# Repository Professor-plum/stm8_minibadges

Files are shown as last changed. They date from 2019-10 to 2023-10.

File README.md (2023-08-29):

# stm8_minibadges
Repository of mini badges using the stm8s001j3.

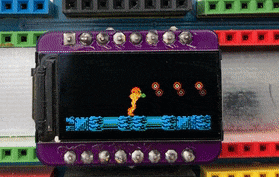
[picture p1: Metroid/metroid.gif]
Metroid

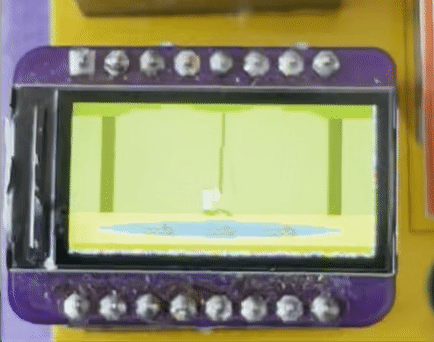
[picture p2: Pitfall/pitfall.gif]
Pitfall

Doom
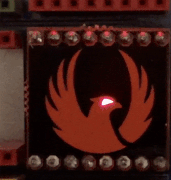
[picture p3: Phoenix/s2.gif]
Phoenix


This repo contains all the source code and eagle files for the mini badges I've designed using the STM8S001J3 microprocessor. I've loved this little chip as it's cheaper than an ATTiny and extremely versatile. The package design leaves a bit to be desired as it wastes one pin for a required cap and the pin 1 marking is horrible but for $.23 you can't complain much.

## Assembly

I'd recommend soldering the LCD down first, followed by the STM8 chip (note the orientation) then the resistor and capacitor. Finally, solder on the pin header legs once all the surface mount components are down. 

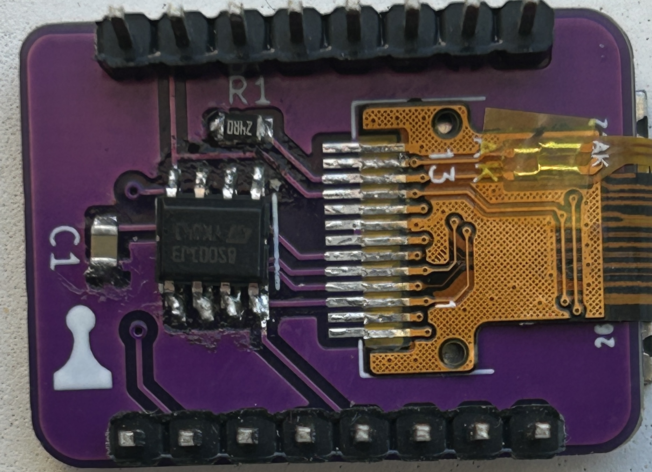
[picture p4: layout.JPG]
Layout


## Flashing

In all my stm8 projects I do bare metal programming and utilize no libraries (I'm usually wanting to make the most of that 8K flash)

There’s also a lot of code reuse between these projects. I could probably do better at managing that, meh...

The following tools are required to compile and flash the chips:
* [ST-Link V2](http://www.ebay.com/sch/i.html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)
* [sdcc](https://sourceforge.net/projects/sdcc/files/snapshot_builds/)
* [stm8flash](https://github.com/vdudouyt/stm8flash)

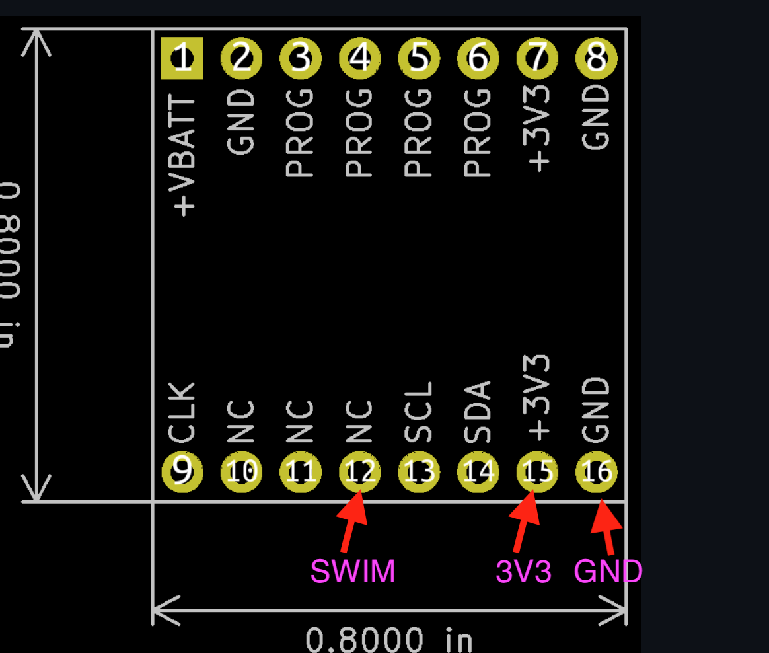
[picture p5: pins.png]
Pinmap


To flash the badge there are only three that need to be connected from the ST-Link to the minibadge. 
* That is 3V3 to the lower 3V
* GND to ether GND
* SWIM to NC12 (4th pin from the right on the bottom row)

Usually, the process for compiling and flashing is the same for all projects. That is:

```bash
>sdcc -lstm8 -mstm8 --out-fmt-ihx main.c
>stm8flash -c stlinkv2 -p stm8s001j3 -w main.ihx
```

The stm8flash command usually needs to be executed twice, the first rarely takes.
A successful flash outputs something similar to this

```
Determine FLASH area
Due to its file extension (or lack thereof), "main.ihx" is considered as INTEL HEX format!
4456 bytes at 0x8000... OK
Bytes written: 4456
```

I apologize for the lack of code comments but I don’t really care enough to do something about it :/

The colors may be inverted depending on the TFT LCD type you have. The simple fix is to locate the line `ST7735_Write(ST7735_INVOFF, CMD);` in the main.c file and change it to `ST7735_Write(ST7735_INVON, CMD);` or vice versa. Then recompile and reflash.

The official documentation for this chip can be found at https://www.st.com/resource/en/datasheet/stm8s001j3.pdf

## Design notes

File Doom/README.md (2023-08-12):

# Doom Mini Badge!

Doom

## Bill of Materials 
* 0.96" 80x160 ST7735 TFT LCD Display
* STMS001J3
* 22 Ohm 0603 Resistor
* 1uF 0603 Capacitor
* Pin headers

Same hardware as the Metroid Mini Badge

Doom face from orignal game. Shows random expression (always full health)

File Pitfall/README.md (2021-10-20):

# Pitfall Mini Badge!

Pitfall

## Bill of Materials 
* 0.96" 80x160 ST7735 TFT LCD Display
* STMS001J3
* 22 Ohm 0603 Resistor
* 1uF 0603 Capacitor
* Pin headers

Same hardware as the Metroid Mini Badge

The sketch is a tribute to the original Atari Pitfall! programers who wrote the whole game in 4K. (This minibadge takes more than that just for this short animation)

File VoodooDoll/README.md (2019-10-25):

# Voodoo Doll SOA

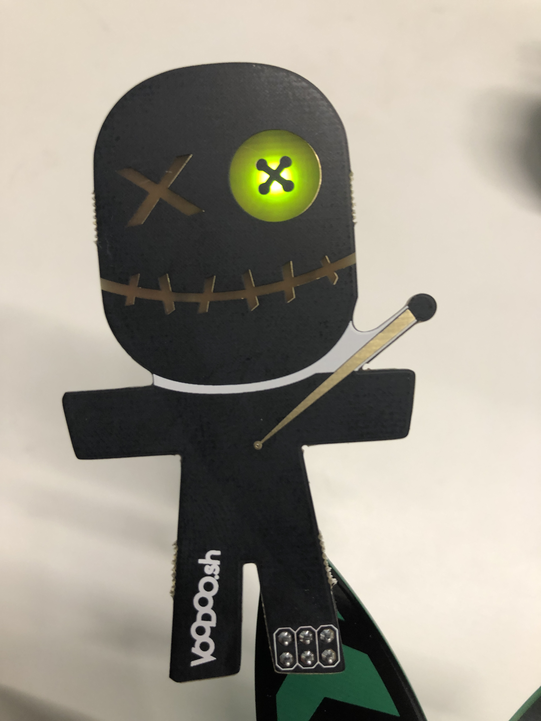
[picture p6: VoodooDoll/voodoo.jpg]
Voodoo Doll


This isn't a mini badge per say but it’s very similar and based off the same chip so I’m including it. I can’t seem to locate the Eagle files for this project but once I do I’ll add them to the repo.

## Bill of Materials
* STMS001J3
* LSG T77K-JL Red/Green LED
* 2x 1K Ohm 0603 Resistor
* 1M Ohm 0603 Resistor
* 1uF 0603 Capacitor
* Cr2032 battery holder (optional)
* 2x3 pin header (optional if using battery)

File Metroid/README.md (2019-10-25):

# Metroid Mini Badge!

Metroid

## Bill of Materials 
* 0.96" 80x160 ST7735 TFT LCD Display
* STMS001J3
* 22 Ohm 0603 Resistor
* 1uF 0603 Capacitor
* Pin headers

The 8K of flash isn't enough space to hold 65536 color sprites for the full animation. since the NES only used 16 colors I'm storing 2 pixels per byte (4 bits each).  The convert.py script does this for me.

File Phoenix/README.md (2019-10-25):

# Phoenix mini badge

Phoenix

This badge had a CTF associated with it. The badge face is touch sensitive and would display a URL on the main badge when touched. There were some issues with the 2019 SAINTCON badge and the link would display in like 1:100 touches.

The eye slowly pulses normally and blinks rapidly when touched

## Bill of Materials
* STM8S001J3
* LS T77K-K1 Red LED
* 470 Ohm 1206 Resistor
* 1M Ohm 1206 Resistor
* 1uF 1206 Capacitor
* pin headers

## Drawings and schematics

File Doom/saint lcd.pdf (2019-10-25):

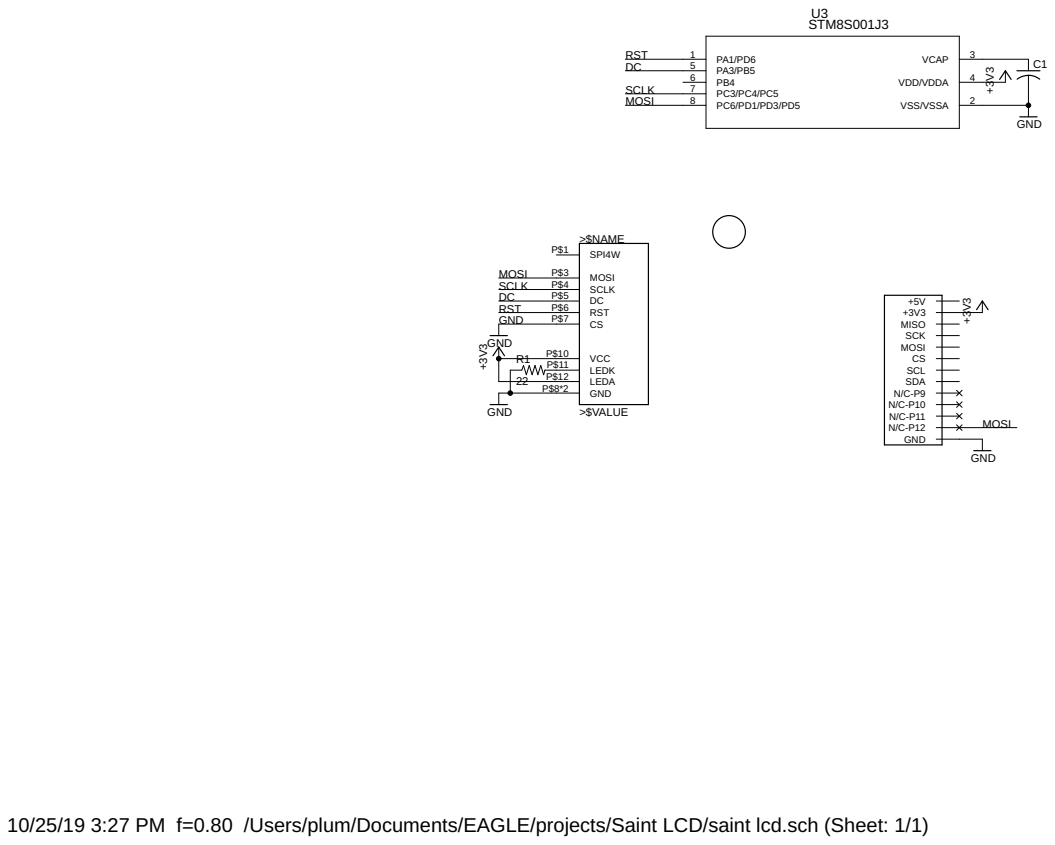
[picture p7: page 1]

10/25/19 3:27 PM f=0.80 /Users/plum/Documents/EAGLE/projects/Saint LCD/saint lcd.sch (Sheet: 1/1)

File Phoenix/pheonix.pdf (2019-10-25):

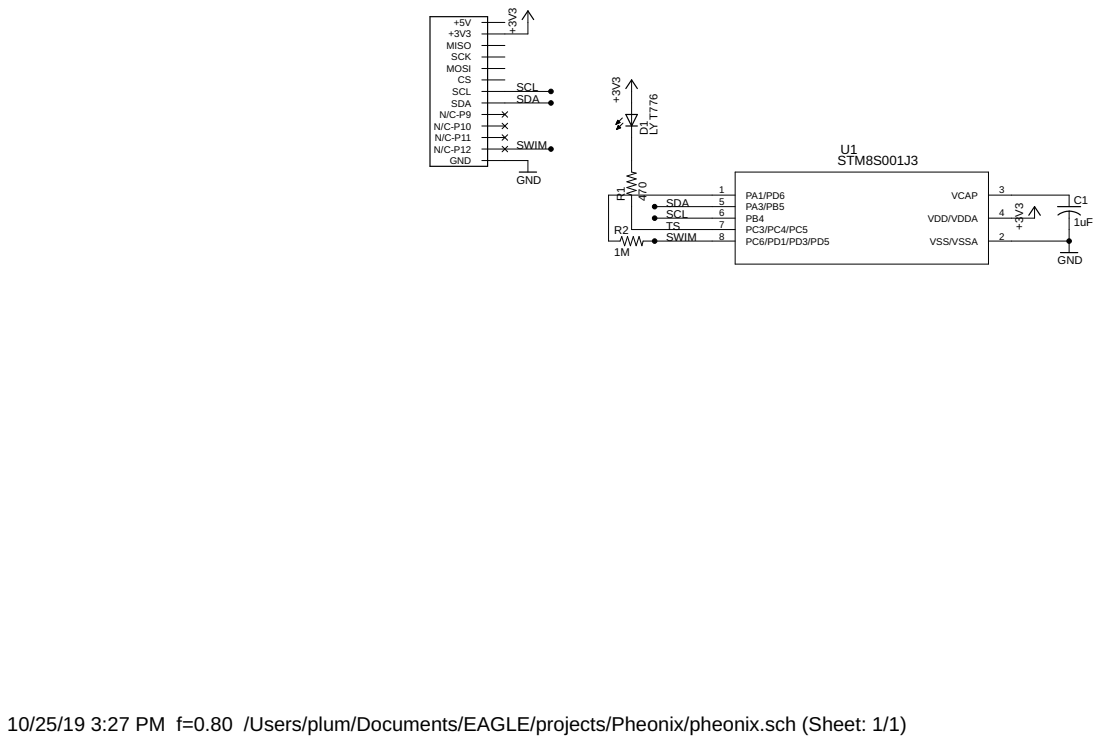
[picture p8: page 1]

10/25/19 3:27 PM f=0.80 /Users/plum/Documents/EAGLE/projects/Pheonix/pheonix.sch (Sheet: 1/1)

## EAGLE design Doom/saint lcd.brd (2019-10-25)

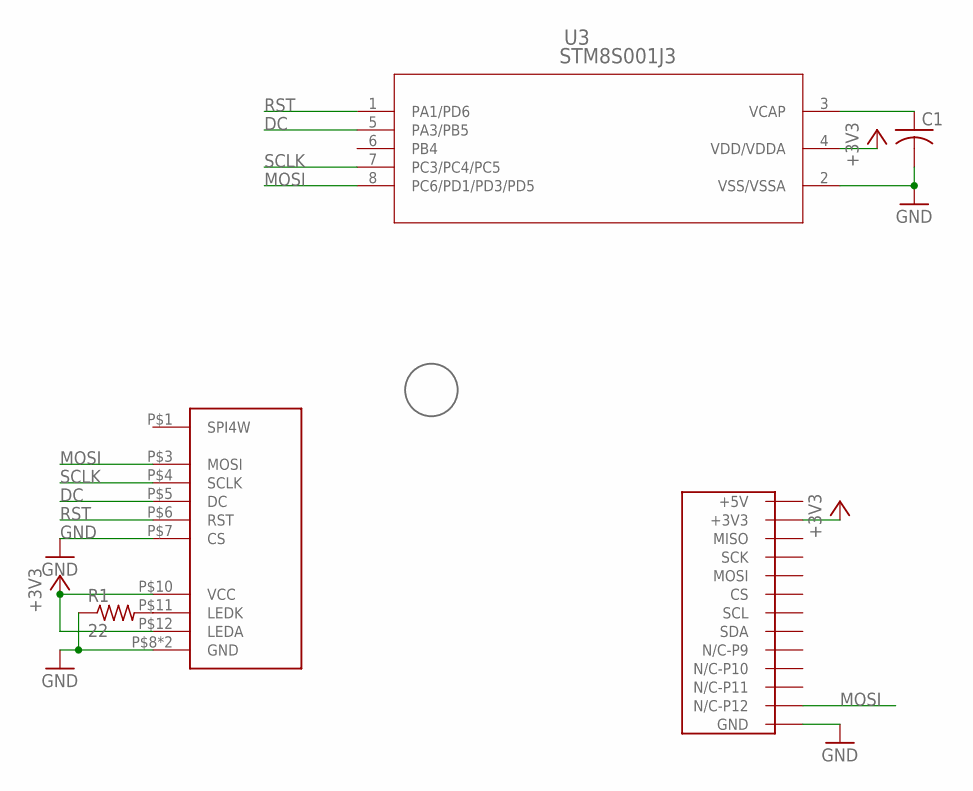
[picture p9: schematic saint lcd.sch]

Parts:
C1: C-USC0603; C0603
R1: 22; R0603
U3: STM8S001J3; SOD8N_4P9X6
U$1: BADGE64FOOTPRINT; BADGE64-FOOTPRINT
U$2: FPC13
U$3: PLUM

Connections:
+3V3: U3.4 (VDD/VDDA), U$1.+3V3-P7 (+3V3), U$1.+3V3-P15 (+3V3), U$2.P$10 (VCC), U$2.P$12 (LEDA)
+5V: U$1.+5V
DC: U3.5 (PA3/PB5), U$2.P$5 (DC)
GND: C1.2, R1.1, U3.2 (VSS/VSSA), U$1.GND-P2 (GND), U$1.GND-P8 (GND), U$1.GND-P16 (GND), U$2.P$7 (CS), U$2.P$8 (GND), U$2.P$13 (GND)
MOSI: U3.8 (PC6/PD1/PD3/PD5), U$1.NC-P12 (N/C-P12), U$2.P$3 (MOSI)
unnamed: R1.2, U$2.P$11 (LEDK)
unnamed: C1.1, U3.3 (VCAP)
RST: U3.1 (PA1/PD6), U$2.P$6 (RST)
SCLK: U3.7 (PC3/PC4/PC5), U$2.P$4 (SCLK)

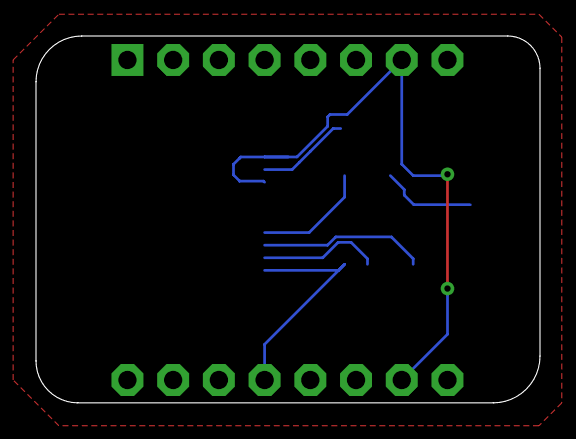
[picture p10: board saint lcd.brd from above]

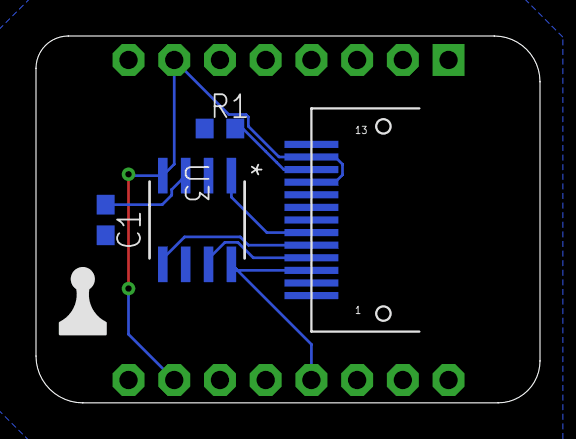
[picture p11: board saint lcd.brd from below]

Board: 2 copper layers, 28.0 x 20.4 mm, 6 parts (5 on the bottom side), 8 nets.

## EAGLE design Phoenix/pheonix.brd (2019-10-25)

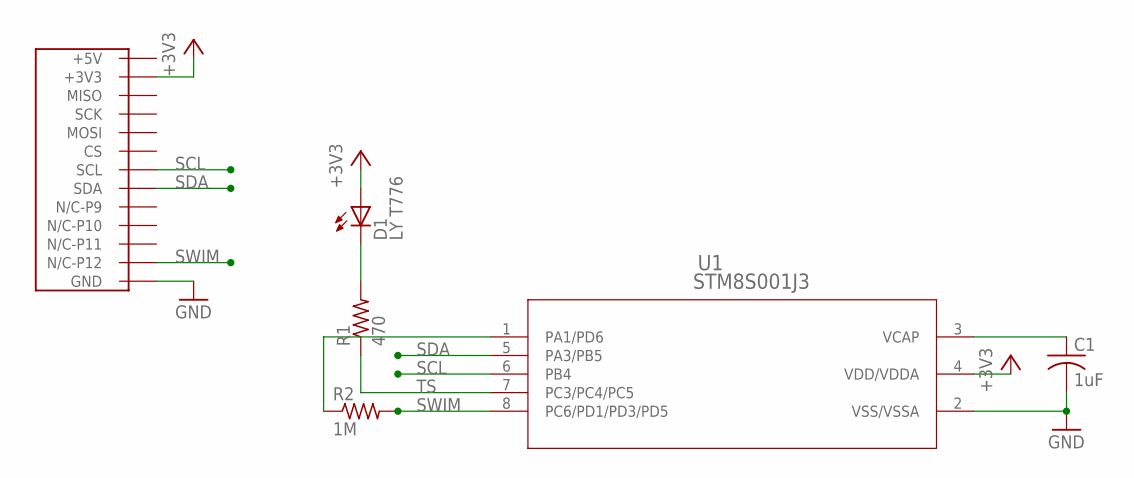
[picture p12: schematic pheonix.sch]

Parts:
C1: 1uF; C1206
D1: LY T776; P-LCC-2-TOPLED-RG-SMALL
R1: 470; M1206
R2: 1M; M1206
U1: STM8S001J3; SOD8N_4P9X6
U$1: BADGE64FOOTPRINT; BADGE64-FOOTPRINT

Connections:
+3V3: D1.A, U1.4 (VDD/VDDA), U$1.+3V3-P7 (+3V3), U$1.+3V3-P15 (+3V3)
+5V: U$1.+5V
GND: C1.2, U1.2 (VSS/VSSA), U$1.GND-P2 (GND), U$1.GND-P8 (GND), U$1.GND-P16 (GND)
unnamed: D1.C, R1.2
unnamed: R1.1, U1.7 (PC3/PC4/PC5)
unnamed: C1.1, U1.3 (VCAP)
SCL: U1.6 (PB4), U$1.SCL
SDA: U1.5 (PA3/PB5), U$1.SDA
SWIM: R2.2, U1.8 (PC6/PD1/PD3/PD5), U$1.NC-P12 (N/C-P12)
TS: R2.1, U1.1 (PA1/PD6)

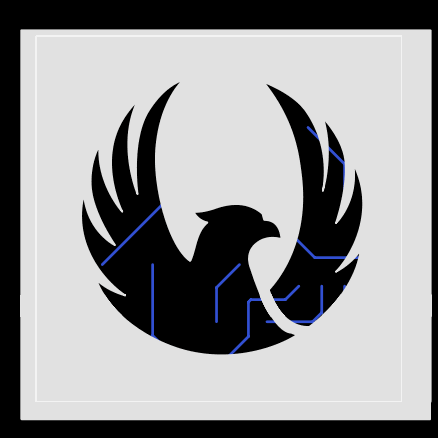
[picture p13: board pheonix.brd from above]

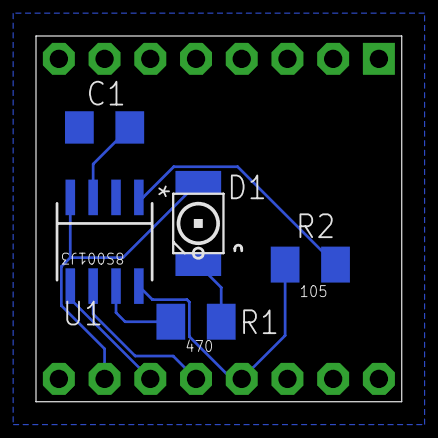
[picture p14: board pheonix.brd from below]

Board: 2 copper layers, 20.3 x 20.3 mm, 6 parts (5 on the bottom side), 9 nets.

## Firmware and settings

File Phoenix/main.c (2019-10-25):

#include <stdint.h>
#include <stdio.h>

#include "stm8s.h"

#define TSPAN	15
#define SINC	256
const uint16_t sin_tbl[] = {
266, 277, 287, 298, 310, 321, 333, 345, 357, 370, 382, 395, 408, 422, 435, 449, 463, 477, 491, 506, 520, 535, 550, 565, 580, 595, 610, 625, 640, 655, 670, 685, 700, 715, 729, 744, 758, 772, 786, 800, 813, 826, 839, 851, 863, 875, 886, 897, 907, 917, 926, 935, 943, 950, 957, 964, 969, 974, 979, 983, 986, 988, 990, 991, 991, 991, 990, 988, 986, 983, 979, 974, 969, 964, 957, 950, 943, 935, 926, 917, 907, 897, 886, 875, 863, 851, 839, 826, 813, 800, 786, 772, 758, 744, 729, 715, 700, 685, 670, 655, 640, 625, 610, 595, 580, 565, 550, 535, 520, 506, 491, 477, 463, 449, 435, 422, 408, 395, 382, 370, 357, 345, 333, 321, 310, 298, 287, 277, 266, 256, 246, 236, 227, 218, 209, 200, 191, 183, 175, 167, 160, 153, 146, 139, 132, 126, 119, 113, 108, 102, 97, 91, 86, 82, 77, 72, 68, 64, 60, 56, 52, 49, 45, 42, 39, 36, 33, 31, 28, 26, 23, 21, 19, 17, 15, 13, 12, 10, 9, 8, 6, 5, 4, 3, 3, 2, 1, 1, 0, 0, 0, 0, 0, 0, 0, 0, 0, 1, 1, 2, 3, 3, 4, 5, 6, 8, 9, 10, 12, 13, 15, 17, 19, 21, 23, 26, 28, 31, 33, 36, 39, 42, 45, 49, 52, 56, 60, 64, 68, 72, 77, 82, 86, 91, 97, 102, 108, 113, 119, 126, 132, 139, 146, 153, 160, 167, 175, 183, 191, 200, 209, 218, 227, 236, 246, 256,
};


#define SENSE_PIN (1<<1)
#define LOAD_PIN (1<<6)
#define I2C_SLAVE_ADDR	0x41


typedef enum {
    Idle,
    Ready,
    SentType,
    SendingSize,
    SentSize,
    SendingMessage,
    SentMessage,
} i2cState;

i2cState _is = Idle;

uint8_t i2c_idx=0;
const char disp2[] = "http://bit.ly/Stage2SC";

void opt_write() {
    /* new value for OPT5 (default is 0x00) */
    uint8_t opt2 = 0x01;
    /* unlock EEPROM */
    FLASH_DUKR = FLASH_DUKR_KEY1;
    FLASH_DUKR = FLASH_DUKR_KEY2;
    while (!(FLASH_IAPSR & (1 << FLASH_IAPSR_DUL)));
    /* unlock option bytes */
    FLASH_CR2 |= (1 << FLASH_CR2_OPT);
    FLASH_NCR2 &= ~(1 << FLASH_NCR2_NOPT);
    /* write option byte and it's complement */
    OPT2 = opt2;
    NOPT2 = ~opt2;
    /* wait until programming is finished */
    while (!(FLASH_IAPSR & (1 << FLASH_IAPSR_EOP)));
    /* lock EEPROM */
    FLASH_IAPSR &= ~(1 << FLASH_IAPSR_DUL);
}

unsigned int clock(void)
{
	unsigned char h = TIM1_CNTRH;
	unsigned char l = TIM1_CNTRL;
	return((unsigned int)(h) << 8 | l);
}

void init_clock(void) {
	CLK_CKDIVR = 0x00; // Set the frequency to 2 MHz
	CLK_PCKENR1 = 0xb9; // Enable Timers 1, 2, 4, i2c
	CLK_PCKENR2 = 0x73; //off
	//CLK_PCKENR1 = 0xFF; // Enable all peripherals
}

void init_tim1(void) {
	// Configure timer
	TIM1_PSCRH = 0x3e; // 1000 ticks per second 1Khz
	TIM1_PSCRL = 0x80;
	TIM1_CR1 = 0x01; // Enable timer
	

	//TIM1_CNTRH = 0; //reset counter
	//TIM1_CNTRL = 0;
}

void init_tim2(void) {
	TIM2_PSCR = 0x05; //Prescaler 32
	TIM2_ARRH = 0x03; //Autoreload 1000
	TIM2_ARRL = 0xe8;

	TIM2_CCER1 = 0x03; //Enable Channel 1 output | Compare low
	TIM2_CCMR1 = 0x60; // Compare mode PWM1 (changed from 0x78)
	TIM2_EGR |= 0x01;
	TIM2_CR1 = 0x81; //Enable timer2
}

inline void port_init() {
    PA_DDR |= 0x4; // PA2
	PA_CR1 |= 0x4;
	PA_ODR &= ~0x4;

	PB_DDR |= 0xcf; //PB1, PB2, PB3, PB6, PB7
	PB_CR1 |= 0xcf;
	PB_ODR &= ~0xcf;

	PC_DDR |= 0x86; //PC1, PC2, PC7
	PC_CR1 |= 0x86;
	PC_ODR &= ~0x86;

	PD_DDR |= 0x95; //PD0, PD2, PD4, PD7
	PD_CR1 |= 0x95;
	PD_ODR &= ~0x95;

	PE_DDR |= 0x40; //PE5
	PE_CR1 |= 0x40;
	PE_ODR &= ~0x40;

	PF_DDR |= 0x80; //PF7
	PF_CR1 |= 0x80;
	PF_ODR &= ~0x80;

}

void uart_init() {
    /* Configure RX and TX pins */
    //PD_DDR = 0xBF;
    //PD_CR1 = 0xFF;
    PD_DDR |= (1<<5); //PD5 output
    PD_CR1 |= (1<<5); //PD5 push-pull
    
    /* Enable TX */
    UART1_CR2 = UART_CR2_TEN;
    /* 1 stop bit */
    UART1_CR3 &= ~(UART_CR3_STOP1 | UART_CR3_STOP0);
    /* 9600 baud, 16MHz, Error:0.08%   */
    UART1_BRR2 = 0x03;
    UART1_BRR1 = 0x68;
}

void tim2_pwm1(uint16_t val) {
	TIM2_CCR1H = val >> 8;
	TIM2_CCR1L = val & 0xff;

}

#define CAP_TIMEOUT	256 //should be muchlower now

long readCapTouch() {
	//long i;
	PD_ODR |= LOAD_PIN; //send high
	PD_ODR &= ~SENSE_PIN; //low
	PD_DDR |= SENSE_PIN; //output
	PD_CR1 |= SENSE_PIN; //push/pull
	//for (i=0; i<100; ++i)
	//	__asm__ ("nop"); 
	
	PD_CR1 &= ~SENSE_PIN; //float
	PD_DDR &= ~SENSE_PIN; //recv input

	/*//PB_ODR &= ~(1<<4); //send low
	//PC_DDR &= ~((1<<3) | (1<<4) | (1<<5)); //PC3,4,5 input
	PC_DDR |= (1<<3) | (1<<4) | (1<<5); //recv ouput
	PC_ODR &= ~(1<<4); //recv low
	PC_DDR &= ~((1<<3) | (1<<4) | (1<<5)); //PC3,4,5 input
	for (i=0; i<1000; ++i)
		__asm__ ("nop"); 
	PB_ODR |= (1<<4); //send high
	PB_CR1 |= (1<<4);*/

	long count=0;
	while ((PD_IDR & SENSE_PIN)==0) {
		count++;
		if (count > CAP_TIMEOUT){
			break;
		}
	}

	PD_ODR |= SENSE_PIN; //high
	PD_DDR |= SENSE_PIN; //output
	PD_CR1 |= SENSE_PIN; //push/pull
	PD_ODR &= ~LOAD_PIN; //send low
	
	//for (i=0; i<100; ++i)
	//	__asm__ ("nop"); 
	
	PD_CR1 &= ~SENSE_PIN; //float
	PD_DDR &= ~SENSE_PIN; //recv input

	/*//PC_ODR |= (1<<4); //recv high
	PC_DDR |= (1<<3) | (1<<4) | (1<<5); //recv ouput
	PC_ODR |= (1<<4); //recv high
	for (i=0; i<1000; ++i)
		__asm__ ("nop"); 
	PC_DDR &= ~((1<<3) | (1<<4) | (1<<5)); //PC3,4,5 input
	PB_ODR &= ~(1<<4); //send low
	PB_CR1 &= ~(1<<4);*/
	
	long count2=0;
	while ((PD_IDR & SENSE_PIN)) {
		count2++;
		if (count2 > CAP_TIMEOUT)
			break;
	}
	//printf("Measure %ld + %ld\r\n", count, count2);
	return count+count2;
}

long rawCapSample(int count) {
	long total = 0;
	for (int i=0; i< count; ++i) {
		long t = readCapTouch();
		total += t;
	}
	return total;
}

/**
 * Initialize I2C at 100KHz standard mode.
 */
void i2c_init() {
    /* Disable I2C */
    I2C_CR1 &= ~I2C_CR1_PE;
    //I2C_CR1 |= I2C_CR1_ENGC;
    I2C_FREQR = 0x16;
    
    /* Configure I2C clock */
    I2C_CCRH = 0;
    I2C_CCRL = 0x50;
    I2C_TRISER = 17;

    /* Must always be written as 1 */
    I2C_OARH = I2C_OARH_ADDCONF;
    /* 7-bit slave address */
    I2C_OARL = (I2C_SLAVE_ADDR << 1) ;
    //I2C_OARH &= ~I2C_OARH_ADDMODE;

    /* Enable I2C interrupts */
    I2C_ITR |= (I2C_ITR_ITBUFEN|I2C_ITR_ITEVTEN|I2C_ITR_ITERREN);
    /* Configuration ready, re-enable I2C */
    
    I2C_CR1 |= I2C_CR1_PE;
    I2C_CR2 |= I2C_CR2_ACK;
    
}

void flipLed() {
    if ((clock()%100) >= 50) {
        //(clock()%2). ((m%10) >4)
        tim2_pwm1(999);
    } else {
        tim2_pwm1(0);
    }
}

int putchar(int c)
{
    while(!(UART1_SR & UART_SR_TXE));
    
    UART1_DR = c;
    return c;
}

void main(void)
{
    unsigned long i = 0;
    unsigned long j = 0;

    //for(i = 0; i < 3; i++)
       for(j = 0; j< 147456; j++); // Sleep for reset

    init_clock();
    opt_write();
    init_tim2();
    init_tim1();
	
    //port_init();
    //uart_init();
    i2c_init();
	
    // Set LED ports for output
    PC_DDR |= 0x20; //PA1 & PA3 output
    PC_CR1 |= 0x20; //PA1 & PA3 push-pull
    PC_ODR &= ~0x20; //PA1 & PA3 lights off
    //PD_DDR &= ~(1<<6); // input for PD6

	
    //load init low
    PD_ODR &= ~LOAD_PIN; //low
    PD_DDR |= LOAD_PIN; //output
    PD_CR1 |= LOAD_PIN; //push-pull

    PD_CR1 |= SENSE_PIN; //push-pull
    PD_ODR &= ~SENSE_PIN; //low
    PD_DDR |= SENSE_PIN; //output
    
    __asm__ ("rim"); //enable interrupts
    int touch=0;
    
    while(1) {
        
        int at = (clock()/TSPAN)%SINC;
        
        long cap = rawCapSample(30);
        if (cap > 1000) {
            if (!touch) {
                //CLK_PCKENR1 &= ~0x10; //disables timer 4
                tim2_pwm1(0);
                touch = 1;
                if (_is == Idle)
                    _is = Ready;
            }
            if ((clock()%100) >= 50) {
                //(clock()%2). ((m%10) >4)
                tim2_pwm1(999);
            } else {
                tim2_pwm1(0);
            }
        } else if (touch) {
            touch = 0;
            PC_ODR |= 0x38; //PA1 high (off)
            //CLK_PCKENR1 |= 0x10; //re-enable timer 4
        }
        else
            tim2_pwm1(sin_tbl[at]);
    }

}


const uint8_t disp1[33] = {3, 0xFF, 0xFF, 0xFC, 0xF0, 0xC0, 0, 0, 0x7E, 0x50, 0x50, 0, 0x7E, 2, 2, 0, 0x7C, 2, 2, 0x7C, 0, 0x7E, 0x20, 0x10, 0x20, 0x7E, 0, 0, 0xC0, 0xF0, 0xFC, 0xFF};


/* I2C interrupt service routine for master transfer */

void i2c_isr(void) __interrupt(INT_I2C) {
    uint8_t r= I2C_SR1;
    if (r & I2C_SR1_ADDR) {
        /* Address matched, */
        switch(_is) {
            case Ready:
                break;
            default:
                break;
        }
        r = I2C_SR3;
    } else if (r & I2C_SR1_STOPF) {
        I2C_CR2 |= I2C_CR2_ACK;
    } else if (r & I2C_SR1_TXE) {
        /* Data reg empty, send more */
        /* Write byte to data register */
        switch(_is) {
            case Ready:
		if (i2c_idx == 0)
                	I2C_DR = 2;
		else if (i2c_idx == 1)
			I2C_DR = sizeof(disp2)-1;
		else if (i2c_idx < sizeof(disp2)+1)
			I2C_DR = disp2[i2c_idx-2];
		else
			I2C_DR = 0;
		i2c_idx++;
                break;
            case SentType:
            case SendingSize:
                I2C_DR = sizeof(disp2)-1;
                break;
            case SentSize:
            case SendingMessage:
                if (i2c_idx < sizeof(disp2)) {
                    I2C_DR = disp2[i2c_idx++];
                }
                else {
                    I2C_DR=0;
                }
                break;
            default:
                I2C_DR=0;
        }
    } else if (r & I2C_SR1_BTF) {
    } else if (r & I2C_SR1_RXNE) {
        /* Receive a byte */
        // we never actually use this....
        I2C_CR2 |= I2C_CR2_STOP;
        //_is = Ready;
        char rr = I2C_DR;
    } else if (I2C_SR2 & I2C_SR2_AF) {
        switch (_is) {
	case Ready:
		_is=SentType;
		break;
	case SentType:
		_is = SentSize;
		i2c_idx=0;
		break;
	case SentSize:
		_is = SendingMessage;
		break;
	case SendingMessage:
		_is = Idle;
		i2c_idx=0;
		break;
	}
         /* send complete; */
        I2C_SR2 &= ~I2C_SR2_AF;
    } else {
        I2C_SR2 = 0;
        /* handle any errors */
    }
}

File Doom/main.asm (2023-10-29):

;--------------------------------------------------------
; File Created by SDCC : free open source ISO C Compiler 
; Version 4.3.0 #14184 (Mac OS X ppc)
;--------------------------------------------------------
	.module main
	.optsdcc -mstm8
	
;--------------------------------------------------------
; Public variables in this module
;--------------------------------------------------------
	.globl _doom8_raw
	.globl _doom7_raw
	.globl _doom6_raw
	.globl _doom5_raw
	.globl _doom4_raw
	.globl _doom3_raw
	.globl _doom2_raw
	.globl _doom1_raw
	.globl _pallet
	.globl _ST7735_Write
	.globl _SPI_write
	.globl _SPI_init
	.globl _main
	.globl _drawFace
	.globl _init_clock
	.globl _clock
	.globl _rand
	.globl _ST7735_Write16
	.globl _ST7735_SetAddrWindow
	.globl _ST7735_Init
	.globl _ST7735_Clear
;--------------------------------------------------------
; ram data
;--------------------------------------------------------
	.area DATA
;--------------------------------------------------------
; ram data
;--------------------------------------------------------
	.area INITIALIZED
;--------------------------------------------------------
; Stack segment in internal ram
;--------------------------------------------------------
	.area SSEG
__start__stack:
	.ds	1

;--------------------------------------------------------
; absolute external ram data
;--------------------------------------------------------
	.area DABS (ABS)

; default segment ordering for linker
	.area HOME
	.area GSINIT
	.area GSFINAL
	.area CONST
	.area INITIALIZER
	.area CODE

;--------------------------------------------------------
; interrupt vector
;--------------------------------------------------------
	.area HOME
__interrupt_vect:
	int s_GSINIT ; reset
;--------------------------------------------------------
; global & static initialisations
;--------------------------------------------------------
	.area HOME
	.area GSINIT
	.area GSFINAL
	.area GSINIT
	call	___sdcc_external_startup
	tnz	a
	jreq	__sdcc_init_data
	jp	__sdcc_program_startup
__sdcc_init_data:
; stm8_genXINIT() start
	ldw x, #l_DATA
	jreq	00002$
00001$:
	clr (s_DATA - 1, x)
	decw x
	jrne	00001$
00002$:
	ldw	x, #l_INITIALIZER
	jreq	00004$
00003$:
	ld	a, (s_INITIALIZER - 1, x)
	ld	(s_INITIALIZED - 1, x), a
	decw	x
	jrne	00003$
00004$:
; stm8_genXINIT() end
	.area GSFINAL
	jp	__sdcc_program_startup
;--------------------------------------------------------
; Home
;--------------------------------------------------------
	.area HOME
	.area HOME
__sdcc_program_startup:
	jp	_main
;	return from main will return to caller
;--------------------------------------------------------
; code
;--------------------------------------------------------
	.area CODE
;	main.c: 25: static inline void delay_ms(uint16_t ms) {
;	-----------------------------------------
;	 function delay_ms
;	-----------------------------------------
_delay_ms:
	sub	sp, #10
	ldw	(0x05, sp), x
;	main.c: 27: for (i = 0; i < ((F_CPU / 1000UL) * ms); i++)
	clrw	x
	ldw	(0x09, sp), x
	ldw	(0x07, sp), x
00103$:
	ldw	x, (0x05, sp)
	pushw	x
	ldw	x, #0x07d0
	call	___muluint2ulong
	addw	sp, #2
	ldw	(0x03, sp), x
	ldw	(0x01, sp), y
	ldw	x, (0x09, sp)
	cpw	x, (0x03, sp)
	ld	a, (0x08, sp)
	sbc	a, (0x02, sp)
	ld	a, (0x07, sp)
	sbc	a, (0x01, sp)
	jrnc	00105$
;	main.c: 28: __asm__("nop");
	nop
;	main.c: 27: for (i = 0; i < ((F_CPU / 1000UL) * ms); i++)
	ldw	x, (0x09, sp)
	incw	x
	ldw	(0x09, sp), x
	jrne	00103$
	ldw	x, (0x07, sp)
	incw	x
	ldw	(0x07, sp), x
	jra	00103$
00105$:
;	main.c: 29: }
	addw	sp, #10
	ret
;	main.c: 31: unsigned int clock(void)
;	-----------------------------------------
;	 function clock
;	-----------------------------------------
_clock:
	sub	sp, #4
;	main.c: 33: unsigned char h = TIM1_CNTRH;
	ld	a, 0x525e
	ld	xh, a
;	main.c: 34: unsigned char l = TIM1_CNTRL;
	ld	a, 0x525f
;	main.c: 35: return((unsigned int)(h) << 8 | l);
	clr	(0x02, sp)
	clr	(0x03, sp)
	or	a, (0x02, sp)
	rlwa	x
	or	a, (0x03, sp)
	ld	xh, a
;	main.c: 36: }
	addw	sp, #4
	ret
;	main.c: 38: void init_clock(void) {
;	-----------------------------------------
;	 function init_clock
;	-----------------------------------------
_init_clock:
;	main.c: 39: CLK_CKDIVR = 0;//0x18; // Set the frequency to 2 MHz
	mov	0x50c6+0, #0x00
;	main.c: 40: CLK_PCKENR1 = 0x02; //SPI
	mov	0x50c7+0, #0x02
;	main.c: 41: CLK_PCKENR2 = 0x73; //off
	mov	0x50ca+0, #0x73
;	main.c: 43: }
	ret
;	main.c: 45: void drawFace(const uint8_t *face) { //face is a pointer to a 26x30 array of index pixels
;	-----------------------------------------
;	 function drawFace
;	-----------------------------------------
_drawFace:
	sub	sp, #8
	ldw	(0x03, sp), x
;	main.c: 47: ST7735_SetAddrWindow(41, 2, 78, 80);
	push	#0x50
	push	#0x4e
	push	#0x02
	ld	a, #0x29
	call	_ST7735_SetAddrWindow
;	main.c: 49: for (int y=0; y<80; ++y) {
	clrw	x
	ldw	(0x05, sp), x
00107$:
	ldw	x, (0x05, sp)
	cpw	x, #0x0050
	jrsge	00109$
;	main.c: 51: for (int i=0; i<26; ++i) {
	push	#0x03
	push	#0x00
	ldw	x, (0x07, sp)
	call	__divsint
	addw	x, #0x0003
	pushw	x
	ldw	x, #0x001a
	call	__mulint
	ldw	(0x01, sp), x
	clrw	x
	ldw	(0x07, sp), x
00104$:
	ldw	x, (0x07, sp)
	cpw	x, #0x001a
	jrsge	00108$
;	main.c: 52: int idx = face[(3+(y/3))*26+i];
	ldw	x, (0x01, sp)
	addw	x, (0x07, sp)
	addw	x, (0x03, sp)
	ld	a, (x)
	clrw	x
;	main.c: 53: uint16_t c = pallet[idx];
	ld	xl, a
	sllw	x
	ldw	x, (_pallet+0, x)
;	main.c: 54: ST7735_Write16(c);
	pushw	x
	call	_ST7735_Write16
	popw	x
;	main.c: 55: ST7735_Write16(c);
	pushw	x
	call	_ST7735_Write16
	popw	x
;	main.c: 56: ST7735_Write16(c);
	call	_ST7735_Write16
;	main.c: 51: for (int i=0; i<26; ++i) {
	ldw	x, (0x07, sp)
	incw	x
	ldw	(0x07, sp), x
	jra	00104$
00108$:
;	main.c: 49: for (int y=0; y<80; ++y) {
	ldw	x, (0x05, sp)
	incw	x
	ldw	(0x05, sp), x
	jra	00107$
00109$:
;	main.c: 60: }
	addw	sp, #8
	ret
;	main.c: 62: void main(void)
;	-----------------------------------------
;	 function main
;	-----------------------------------------
_main:
	sub	sp, #16
;	main.c: 64: const uint8_t* frames[7] = {doom1_raw, doom3_raw, doom4_raw, doom5_raw, doom6_raw, doom7_raw, doom8_raw};
	ldw	x, #(_doom1_raw+0)
	ldw	(0x01, sp), x
	ldw	x, #(_doom3_raw+0)
	ldw	(0x03, sp), x
	ldw	x, #(_doom4_raw+0)
	ldw	(0x05, sp), x
	ldw	x, #(_doom5_raw+0)
	ldw	(0x07, sp), x
	ldw	x, #(_doom6_raw+0)
	ldw	(0x09, sp), x
	ldw	x, #(_doom7_raw+0)
	ldw	(0x0b, sp), x
	ldw	x, #(_doom8_raw+0)
	ldw	(0x0d, sp), x
;	main.c: 66: init_clock();
	call	_init_clock
;	main.c: 27: for (i = 0; i < ((F_CPU / 1000UL) * ms); i++)
	clrw	y
	clrw	x
00111$:
	cpw	y, #0x8d80
	ld	a, xl
	sbc	a, #0x5b
	ld	a, xh
	sbc	a, #0x00
	jrnc	00105$
;	main.c: 28: __asm__("nop");
	nop
;	main.c: 27: for (i = 0; i < ((F_CPU / 1000UL) * ms); i++)
	incw	y
	jrne	00111$
	incw	x
	jra	00111$
;	main.c: 67: delay_ms(3000);
00105$:
;	main.c: 68: ST7735_Init();
	call	_ST7735_Init
;	main.c: 70: __asm__ ("rim"); //enable interrupts
	rim
;	main.c: 73: ST7735_Clear(RGB(0,0,0));
	clrw	x
	call	_ST7735_Clear
;	main.c: 75: while(1) {
00102$:
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

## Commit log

2019-10-25 Added content
    [pheonix.brd, pheonix.sch, saint lcd.brd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]
2021-10-20 Added pitfall code
    [saint lcd.brd, saint lcd.sch]
2023-08-12 Added Doom guy firmware
    [saint lcd.brd, saint lcd.sch]

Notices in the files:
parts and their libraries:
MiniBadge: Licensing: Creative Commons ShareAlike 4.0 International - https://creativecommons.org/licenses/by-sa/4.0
